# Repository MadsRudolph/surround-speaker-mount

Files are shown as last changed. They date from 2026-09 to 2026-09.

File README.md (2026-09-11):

# Surround speaker wall mount — compact revision 3

The **[Eris E3.5 dorm-room rail adaptation](rail-mount/README.md)** has its own CAD, print files, concrete-through-rail fixing layout and furnished room renders. It provides ±90° pan and 0–60° indexed downward tilt; see its separate prototype and installation notes.

Three printed parts per speaker, identical for left and right. Default cabinet: **150 × 150 × 180 mm**. Designed motion: **continuous ±60° yaw; 0° to −30° pitch in 5° steps**. All CAD coordinates and STL coordinates are millimetres. This is an unqualified prototype: speaker mass, cabinet construction and wall substrate were not supplied; panel height and plug projection remain unconfirmed. There is no assigned safe working load or claim of permanent freedom from droop.

## Download and print

The **[print/](print/)** folder contains the three current, print-oriented STLs. Download **[speaker-mount-print-STLs.zip](speaker-mount-print-STLs.zip)** for all three plus a quick print guide. Print **two of each part** for a left/right pair.

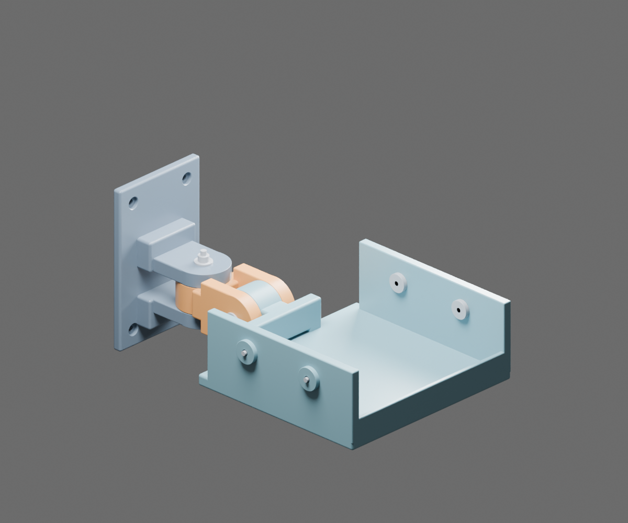
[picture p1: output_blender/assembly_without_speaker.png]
Compact assembly


For live mouse control in FreeCAD, run **[Open_Interactive_Assembly.FCMacro](Open_Interactive_Assembly.FCMacro)**: drag horizontally for pan and vertically for tilt. See [interactive instructions](INTERACTIVE_ASSEMBLY.md).

## Revision 3: indexed tilt, continuous pan

Only the **second (up/down) pivot** has mating radial serrations. The first
(left/right pan) pivot keeps its smooth friction faces and continuous adjustment.
The tilt interface has **72 teeth, giving 5° steps**: 0°, −5°, −10°, −15°, −20°,
−25° and −30°. Three main printed parts are retained; the wall plate is unchanged.

The arm's left inner cheek has a recessed female ring; the cradle's left pitch
face has the matching raised ring. Teeth occupy radii **16–21 mm** of the existing
44 mm joint. Male relief is **0.45 mm**, female groove depth **0.50 mm**. The
trapezoidal profile has broad crests/valleys, with a minimum nominal crest width
of about **0.42 mm** at the inner radius. Small flank/root relief leaves room for
fit variation; zero backlash is not promised.

**Adjustment:** support the speaker, loosen the tilt bolt, slide the cradle toward
the opposite smooth cheek to disengage the teeth, choose a 5° position, seat the
teeth and retighten. Do not force the teeth to ratchet under load. The two nominal
0.3 mm face gaps provide **0.6 mm axial travel from seated to released**, leaving
**0.15 mm nominal tip clearance** at release. Only one face is toothed so release
does not require spreading both clevis ears. Normal clamping still closes the
assembly clearance; tooth engagement and print tolerances must be checked.

The teeth provide positive angular engagement, but the bolt must keep them seated.
Actual rigidity, tooth strength, wear and long-term holding capacity have not been
measured. This is inspired by the radial face-coupling principle described by
[Voith](https://www.voith.com/corp-en/products-services/connection-components-couplings/hirth-serrations.html),
not a rated industrial Hirth coupling.

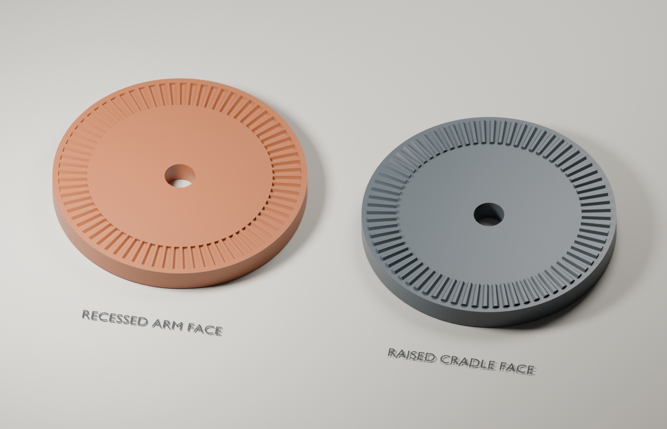
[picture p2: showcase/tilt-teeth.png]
Tilt-only mating tooth profiles on the fit coupons


The two test discs above carry the same tooth profiles as the arm and cradle.
Print the [two fit coupons](print/fit-coupons/) first. Reprint **both the arm and
cradle** for this revision; do not mix a revision 2 smooth part with a revision 3
toothed part. Revision 2 remains available in Git history.

## Compact revision

The pivot spacing is now **55 mm instead of 100 mm (45% shorter)**. The slender connecting span is replaced with a short, wider connector. The speaker rear face sits **147 mm from the wall instead of 197 mm**, a 50 mm reduction. The rear support is only 36 mm high, instead of 102 mm, and the wall plate is 140 mm tall instead of 160 mm. Both full ±60° pan and −30° tilt are retained in the sampled clearance checks. Further wallward shortening consumes the clearance needed when the wide tray is turned 60°.

Your terminal description is interpreted as a centered 40 mm-wide panel (150 − 2×55), with its lower edge 40 mm above the speaker bottom. The tilt pivot is lowered to Z=24 mm, leaving the hardware below the panel. Panel **height is provisionally 60 mm** and connected-plug projection is provisionally **30 mm**. A 50 mm-wide × 70 mm-high clearance box includes 5 mm border margin around that assumed panel, extending 30 mm behind the cabinet. This box is included in the collision checks. The panel is shown in black in Blender; its assumed height is named explicitly in the scene.

The compact geometry reduces the free arm span, but stiffness has not been measured. A lower pivot also changes the gravity torque at downward tilt: the load notes below have been updated rather than assuming every load decreases. `revision_1_original.zip` preserves the previous design locally; the main ZIP contains the current revision 3.

## How this will look

A Blender living-room showcase places the current mount geometry in an illustrative
surround setup with a TV, couch and mounted speakers. The unbranded cabinets match
the design envelope; these are concept renders, not a tested installation.

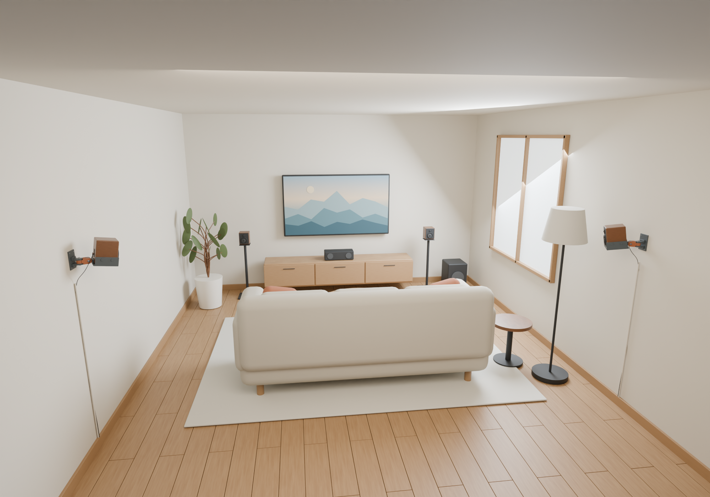
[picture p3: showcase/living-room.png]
Living-room surround setup


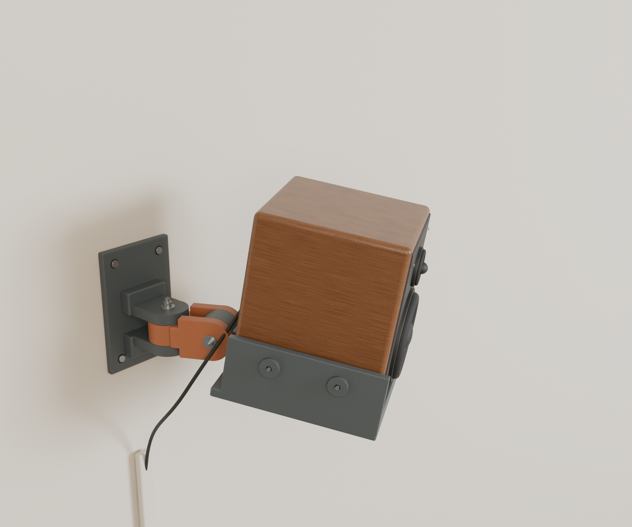
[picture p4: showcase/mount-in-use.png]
Mount with speaker installed


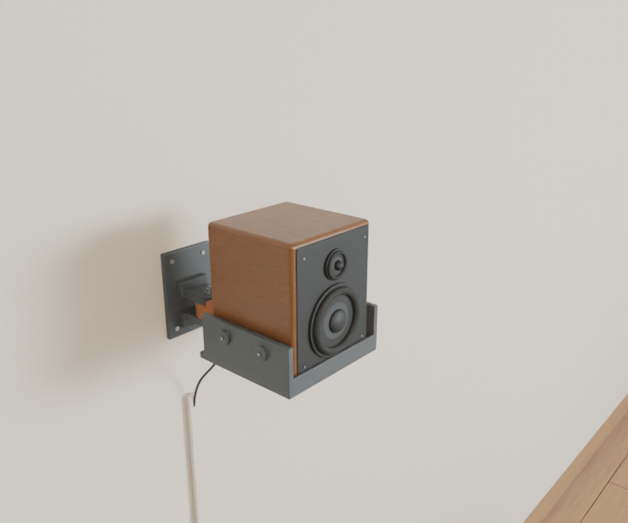
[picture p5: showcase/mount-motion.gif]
Continuous pan and indexed tilt animation


The tilt joint releases axially, changes by 5°, and re-seats. Pan stays continuous.

See [showcase/](showcase/) for the editable Blender scene, rendering script and details.

## Interactive assemblies

Open `output_blender/interactive_assembly.blend` or `output_freecad/interactive_assembly.FCStd` to pose the mount. See [INTERACTIVE_ASSEMBLY.md](INTERACTIVE_ASSEMBLY.md) for the two angle controls and optional FreeCAD slider macro.

## Files and execution

- `parametric_mount.py`: standalone FreeCAD script; Spreadsheet-driven scripted PartDesign bodies.
- `blender_mount.py`: standalone `bpy` model builder, articulated scene, mesh validator, STL exporter and render.
- `output_freecad/`: FCStd, STEP, three print-oriented STL files and CAD validation reports.
- `output_blender/`: Blender scene, assembly image, three print-oriented STL files and mesh report.
- `validate_cad.py`: sampled collision and parameter dependency checks; imports `parametric_mount.py`.
- `geometry_spec.py`: readable geometry reference. Each standalone builder contains its own copy, so neither requires this file. When changing geometry, keep both builders consistent.
- `FREECAD_MCP_SETUP.md`: detection and connection instructions.

Run on this machine:

```bash
cd surround-speaker-mount
python parametric_mount.py
python validate_cad.py
blender --background --factory-startup --python blender_mount.py
```

System Python works here because the script finds `/usr/lib/freecad/lib`. On another OS, run in FreeCAD's Python console:

```python
import sys
sys.path.insert(0, '/absolute/path/to/surround-speaker-mount')
import parametric_mount
parametric_mount.build()
```

Each execution makes a new document/scene and replaces generated output files. Blender preserves other scenes in its current session; use the background command above for a clean deliverable. Rendering uses CPU Cycles. No external assets or Python packages are required by the Blender script.

To reopen the FreeCAD file **with live recomputation**, add the script directory to `sys.path` and import `parametric_mount` before opening the FCStd. Its three bodies use `PartDesign::FeaturePython` backed by OpenCascade solids, not a conventional sketch/Pad/Pocket feature history. Each feature's dimensional properties are expression-linked to `Parameters`. Edit the spreadsheet and recompute. The file's saved shapes remain viewable without the module, but live rebuilding requires it. Re-export after edits:

```python
from pathlib import Path
import FreeCAD as App
import parametric_mount as m
doc = App.ActiveDocument
doc.recompute()
m.export(doc, [doc.getObject(n+'_Geometry') for n in m.NAMES],
         Path('/absolute/path/to/surround-speaker-mount/output_freecad'))
```

| Spreadsheet alias | Default | Effect |
|---|---:|---|
| Speaker_Width | 150 mm | Tray span, sides and clamp locations |
| Speaker_Depth | 150 mm | Tray depth, lip and clamp spacing |
| Speaker_Height | 180 mm | Side rail and clamp height |
| Clamp_Padding_Offset | 2 mm | Cabinet padding allowance |
| Insert_Hole_Diameter | 5.6 mm | Four M4 insert bores |
| Wall_Thickness | 4 mm | Lip; structural plate/rails use twice this value |

Structural thicknesses deliberately exceed 4 mm: tray 10 mm, wall plate 8 mm, side rails 8 mm, clevis ears 12 mm. Numeric parameter bounds reject grossly unsuitable dimensions; they do not certify every combination for clearance or strength. Recheck motion after changing dimensions. Blender uses the `DEFAULTS` dictionary near the top; it does not synchronize automatically with an edited FCStd.

## Geometry and joints

Wall plate: 90 × 140 × 8 mm, with four Ø4.8 mm screw passages on a 60 × 110 mm rectangular pattern. Ø10 × 3 mm counterbores have 0.5 mm radial, 45° mouth chamfers. Rounded edges are generally 1–2 mm. The plate's wall-contact plane is Y=0; its front is Y=8.

Yaw axis is vertical at (0,55,24); pitch axis runs left–right at (0,110,24). Both joints have 44 mm diameter faces and Ø5.3 mm bolt bores. Yaw faces are smooth; one pitch interface carries the revision 3 tooth ring. Wall clevis spacing is 24 mm with a 23.4 mm middle knuckle; pitch clevis spacing is 24.6 mm with a 24 mm tongue. **0.3 mm nominal clearance per mating face**, 0.6 mm total, is taken up when tightening. Washers go outside the ears, not in these gaps. Keep yaw friction faces dry and flat, and keep tilt teeth clean. Yaw is continuous; tilt seats at 5° increments. Software limits are not physical end stops.

The cabinet rests at Z=12 with 2 mm shelf foam. Rear face Y=147, front face Y=297. Lip inner face Y=299 leaves 2 mm for padding; the 26 mm high lip overlaps the speaker bottom by 14 mm. Clamp rail inner faces X=±81 leave 6 mm per side: **4 mm swivel foot plus 2 mm foam**. Side rails end at Z=68.4; clamp centers are Z=48.6 and Y=190/257.5.

The rear bridge ends at Z=36 mm; the measured panel lower edge is Z=52 mm (10 mm shelf + 2 mm foam + 40 mm cabinet offset). The pitch knuckle top is Z=46 mm. The centered terminal region above this is open. The provisional terminal-and-plug clearance box spans X=−25…25, Y=117…147 and Z=47…117 mm. Route wires upward or sideways out of this region, then in a loose service loop clear of both joints. The rectangular clearance check does not simulate a flexible cable or establish a bend radius.

## Hardware BOM

Dimensions below correspond to the default geometry. Count two of each printed part for the pair.

| Hardware | Per speaker | Pair | Specification |
|---|---:|---:|---|
| Yaw and pitch screws | 2 | 4 | M5 × 60 mm socket head cap screws, steel, length under head |
| Joint locknuts | 2 | 4 | M5 nylon-insert locknuts, about 5 mm high |
| Joint load-spreading washers | 4 | 8 | M5, ID 5.3 mm, OD 15 mm, thickness 1.5 mm |
| Clamp screws | 4 | 8 | M4 × 25 mm threaded shaft, commercial ball-ended swivel-pressure screws, detachable feet |
| Swivel pressure feet | 4 | 8 | Ø16 mm, 4 mm effective axial thickness; compatible with selected M4 screws |
| Clamp jam nuts | 4 | 8 | M4, gently lock screw position after setting pressure |
| Heat-set inserts | 4 | 8 | M4, 6 mm long, nominal OD about 6 mm; straight-hole style suitable for selected polymer |
| Wall screws | 4 | 8 | #8 / Ø4.0–4.5 mm, low pan head ≤9.5 mm diameter and ≤3 mm high |
| Wall anchors | As needed | As needed | Matched to substrate, screw and evaluated pullout/shear loads |
| Foam | ~0.8 m | ~1.6 m | 2 mm thick × 20 mm wide closed-cell EVA/EPDM self-adhesive tape |
| Independent retention | 1 | 2 | Rated strap/harness enclosing cabinet, attached to a separate suitable wall fixing |

M5 grip: yaw plastic 48 mm, pitch plastic 48.6 mm; two 1.5 mm washers plus a ~5 mm nut leave roughly 4 mm or 3.4 mm of thread beyond the nut with M5×60. Confirm full nylon engagement with the actual hardware. Nut and head seats remain externally accessible; the model does not rely on printed threads or trapped nuts for the joints.

M4 shaft/foot products have differing length conventions. The model reserves a 12 mm boss/rail depth, 4 mm inward foot thickness and 2 mm foam. Confirm the supplier's drawing gives this working reach and that the foot can be attached **after** threading the shaft through the insert. Do not substitute a bare screw tip against the cabinet. The Blender hardware is an illustrative envelope, not a manufacturing drawing of purchased components.

The 5.6 mm insert hole is a starting value, **not a universal M4 standard**. Buy an insert whose specified installation hole matches your print, or change the parameter. Install from the **cabinet-facing side** so the clamp reaction tends to push the insert into its boss. The 12 mm through-bore leaves travel behind a 6 mm insert. Test an isolated boss cropped in the slicer before printing the full tray. Hole sizing, polymer and boss dimensions determine insert performance; follow the [insert manufacturer's guidance](https://www.spirol.com/resources/white-papers/how-to-design-the-proper-hole-for-heat-ultrasonic-inserts/).

Wall screw **length cannot be finalized without the wall build-up**. Example only: 4.5 × 60 mm screws through the remaining 5 mm counterbore floor and 12.5 mm plasterboard leave 42.5 mm nominal penetration into timber. Verify screw/anchor manufacturer requirements and obstructions. The 60 mm wide hole pattern does not put all four screws into one narrow stud: use structural backing spanning studs, suitable masonry fixing, or a verified anchor arrangement. Do not assume a generic drywall anchor is adequate.

## Printing and assembly

Use PETG or ASA with a validated filament profile. ASA needs suitable enclosure and ventilation; see [Prusa's ASA guidance](https://help.prusa3d.com/article/asa_1809?product=mk3-5) and [PETG guidance](https://help.prusa3d.com/article/petg_2059?product=mini). Neither material makes this a creep-free joint; the tilt teeth also require fit and wear checks. The following settings are design recommendations, not measured strength data:

- 0.4 mm nozzle, 0.20 mm layers; **6 perimeters**, 6–8 top/bottom layers, **45–50% gyroid**.
- Set local solid infill around pivot ears, arm roots, rear cradle supports and insert bosses. At least 4–5 walls and 35% infill as requested; the higher values above provide a more conservative starting point.
- Print all three parts **on their X side**, as already oriented in the exported STLs. The arm is flipped relative to revision 2 so its female tilt face points up; the cradle's male tilt face also points up. This places the main Y–Z cantilever bending plane within printed layers. It reduces the critical delamination tendency; it cannot eliminate every transverse tensile stress in a two-axis bracket.
- Use 0.10–0.12 mm layers through the toothed region and verify that the slicer preserves the teeth. Use support blockers on the serrated face; route supports for the opposite ear from smooth regions or the bed. Print and hand-fit the coupons first.
- Use removable supports under raised rails, upper clevis ears, bosses and horizontal bores; inspect the layer preview. Support is not limited to the build plate if that leaves internal overhangs unsupported. Use a brim and protect friction surfaces when removing supports.

| STL | Print bounding box X × Y × Z |
|---|---|
| Part_1_WallPlate | 140 × 77 × 90 mm |
| Part_2_SwivelArm | 44 × 99 × 48.6 mm |
| Part_3_Cradle | 68.4 × 215 × 186 mm |

A **250 mm bed** is recommended for cradle supports and brim; a 220 mm bed leaves only 5 mm total margin in the long direction before supports/brim. STL files are unitless by convention: import as millimetres, verify these dimensions, and do not auto-scale. Print a second identical set for the opposite surround. Do not mirror only one mating part.

1. Confirm speaker mass, terminal clearance, pressure-foot dimensions and wall fixing design. Measure the printed bores and check slip fits before heating inserts.
2. Remove supports, deburr, and carefully finish M5 holes to 5.3 mm if needed. Do not enlarge insert bores without the insert data sheet. Reject split layers or under-extruded parts.
3. Heat-install four M4 inserts from inside the cradle; use a perpendicular installation tip and allow full cooling. Attach the pressure feet after threading the clamp screws through the inserts.
4. Place two 150 mm foam strips on the shelf, foam on the front lip and rear contact columns, and Ø16 mm foam disks on the four pressure feet. Keep foam away from pivot friction surfaces.
5. Assemble yaw and pitch using M5×60 screws, one washer under each head and one under each locknut. Snug the yaw joint until friction is established. Fully seat the tilt teeth at a 5° position before tightening its bolt. Do not apply a generic steel-joint torque value: the plastic seats and ears are the limiting components.
6. Seat the speaker fully on the padded shelf. Tighten the four pressure screws evenly until it is retained without visible cabinet deflection. Gently snug jam nuts while holding each screw. The shelf and lip carry gravity/sliding loads; clamps are not permission to crush the enclosure.
7. Test the complete assembly with a restrained dummy load close to the floor before wall installation. Establish required holding torque and monitor tilt, ear gap and permanent deformation over an extended dwell at expected room temperature. A short test does not establish long-term life. Add independent cabinet retention for overhead use.
8. Remove the speaker, fasten the plate to the evaluated wall fixings, then reinstall and aim it. Hand-support the speaker while loosening either joint. Keep yaw within ±60° and tilt within 0° to −30° in 5° steps. Disengage the tilt teeth before turning, then seat and retighten. If it drifts, rocks or fails to engage, stop and inspect or redesign the joint instead of overtightening.
9. Reinspect after initial settling and periodically thereafter. Inspect the tilt teeth for incomplete seating, wear, cracking and debris. Printed teeth do not establish maintenance-free holding; nylon locknuts alone do not provide that function.

## Load assessment and verification limits

For a uniformly distributed default cabinet, its center is approximately Y=222, Z=102. Relative to the new pitch pivot, that is 112 mm forward and 78 mm upward. The horizontal pitch lever arm is 112 mm at level and **136 mm at −30°**. Speaker-only torque is therefore **1.099 × mass_kg N·m** at level, rising to **1.334 × mass_kg N·m** at −30°. Wall torque is **2.178 × mass_kg N·m** at level and **2.413 × mass_kg N·m** at −30°. Add the cradle, arm, hardware, cable forces and handling loads. A 2 kg cabinet alone at −30° produces about 2.67 N·m at pitch and 4.83 N·m at the wall; this is not a 2 kg rating.

The original pitch friction-capacity estimate no longer describes the revision 3
load path. Tilt torque now loads the tooth flanks, while bolt preload must resist
separation and keep them engaged. The nominal tooth geometry is not a strength
rating: print accuracy, root stress, uneven tooth contact and polymer creep still
need assessment. Yaw continues to rely on friction. FEA, coupon load tests and a
load-duration test have not been performed.

The CAD validator checks 91 sampled pan/tilt positions (10°/5° increments) against the wall, fixed plate, arm, cradle, cabinet envelope and the provisional terminal/plug envelope. It also changes all six spreadsheet parameters individually and verifies recomputation into single valid solids. This is not continuous swept-volume proof; purchased fasteners, flexible cable loops, foam compression and deformation are excluded. Blender independently checks zero nonmanifold edges, one connected component and positive enclosed volume before STL export. Meshes approximate the analytic CAD fillets, so small volume differences are expected.

Final export verification also re-imported all six STLs into FreeCAD Mesh: all reported closed solids with no nonmanifold edges (`stl_validation.json`). Revision 3 needed no boundary repairs. The Blender script retains a tightly limited small-quad repair for Boolean artifacts, then rejects any remaining nonmanifold geometry. Runtime: FreeCAD 1.1.3, Blender 5.2.0. The local Blender installation emitted an unrelated bundled-addon `cattrs` import warning; model generation, both renders and export checks completed.

The revision 3 tilt validator (`validate_tilt_index.py`) checks all seven indexed
positions at nominal and seated offsets, confirms interference at every half-step
when seated, and checks 61 released positions at 0.5° intervals. It exports the
fit coupons and `output_freecad/tilt_index_validation.json`. These are geometric
checks, not strength or wear measurements.

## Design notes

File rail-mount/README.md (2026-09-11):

# Eris E3.5 mounts for the dorm-room rail — revision 1.1

Two adjustable mounts at the wooden rail's existing height, anchored **through the wood into concrete**. Every fixing axis stays within the rail's 50 mm-high outline. Sized for the original PreSonus Eris E3.5 / E3.5 BT, **141 W × 162 D × 210 H mm**.

This is a complete CAD prototype with print files and sampled geometric verification. It has **no assigned safe working load** and has not undergone physical print-fit, creep, sustained-load or anchor testing. Establish those before installing above the bed.

Revision 1.1 enlarges the two inner tilt-bolt recesses to Ø32 mm so a nominal 4 mm-thick spanner can counterhold the heads. The pivot bores, teeth, cabinet fit and movement envelope are unchanged; only the cradle STL needs replacing if you already printed revision 1.0. Side foam now has a 36 mm-wide tool window above Z=−18 mm relative to the pitch axis.

New files: [1:1 A4 drilling template](cad/drilling-template-A4-100percent.pdf), [adjustable isolated mount scene](render/mount_inspection.blend), [speaker-removed service view](render/mount-service.png), and [bolt/spanner fit coupon](print/fit-coupons/Tilt_Bolt_Tool_Access.stl).

Print the template at **Actual Size / 100%**, and measure both scale bars. It transfers centres only: choose drill diameter and depth from the actual concrete-fixing instructions. Do not drill a Ø14.2 hole in the concrete just because that is the printed sleeve bore.

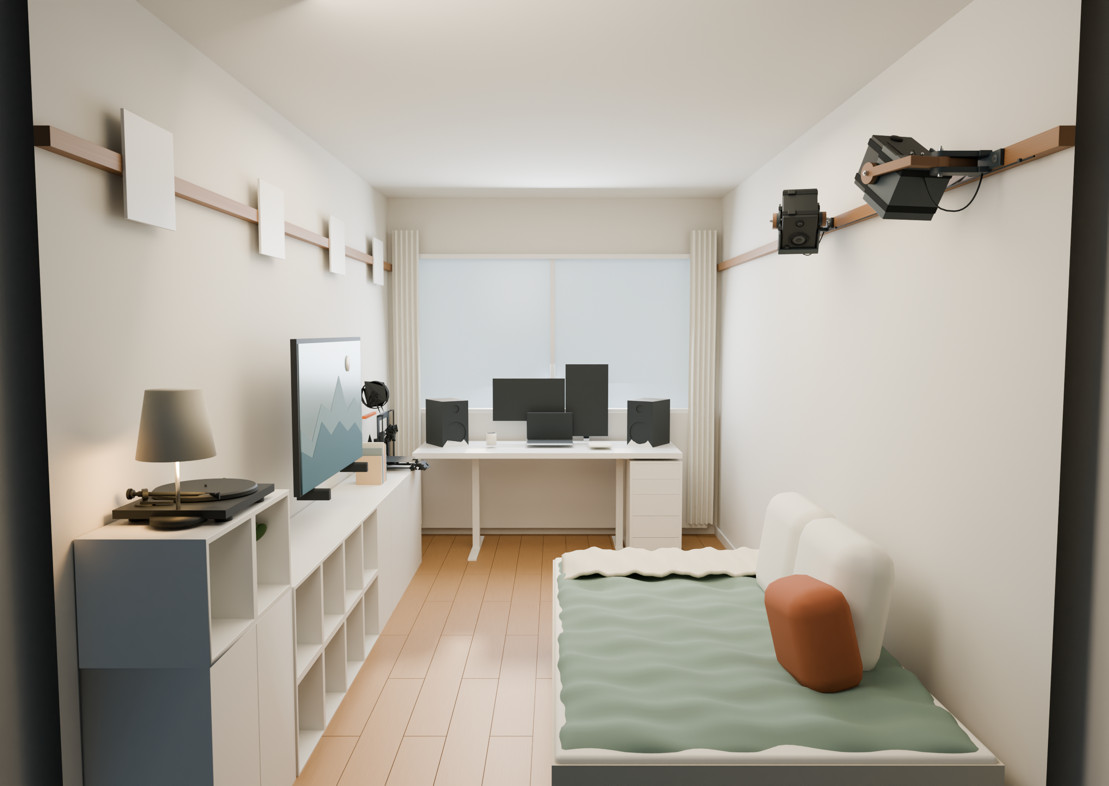
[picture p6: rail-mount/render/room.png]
Room


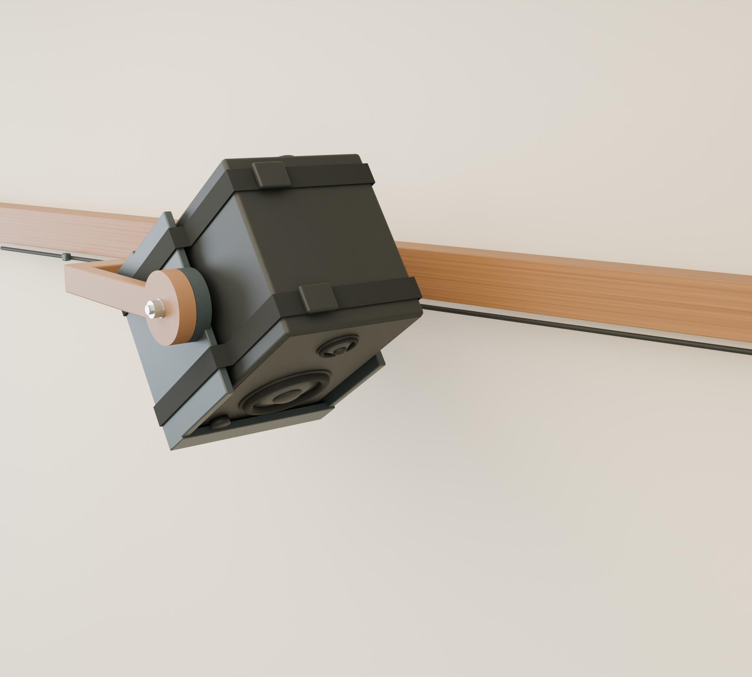
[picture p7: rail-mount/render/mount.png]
Rail mount


## Files

- [Dimensioned drawings and assembly guide](cad/mount-drawings.pdf) — three pages; dimensions, fixing locations, BOM and adjustment.
- [FreeCAD assembly](cad/eris_rail_mount.FCStd) — native solid parts, hardware envelopes and speaker envelope, in the level reference pose.
- [STEP](cad/eris_rail_mount.step) — the three mount solids, in assembly coordinates; import into Fusion.
- [Print files](print/) — one shoe, yoke and cradle per speaker; print **two of each**.
- [Fit coupons](print/fit-coupons/) — new 5-degree tooth profiles, different from revision 3.
- [Editable room scene](render/dorm_room.blend) — actual imported architecture/furniture, both mounts and adjustable aiming controls.

> **Not in the repository.** `render/dorm_room.blend`, `render/room_meshes.json` and the two packaged zips are large binaries, and the room mesh is imported architecture rather than anything in here rebuilds, so they are kept local. Everything needed to print and install the mount — CAD, STEP, STLs, drawings and the drilling template — is committed. Run `rail-mount/package.py` against a local working copy to rebuild the render pack.
- [Room image](render/room.png), [mount detail](render/mount.png), [cutaway](render/overview.png), [both speakers above the bed](render/rail-wall.png).
- [Verification report](cad/validation.json), [solid validation](cad/geometry_validation.json).

## Mount arrangement

The 180 × 46 × 12 mm shoe bears against the timber face. Two fixing centres are **130 mm apart**, on the rail's horizontal centreline. A yaw clevis projects into the room; a U-shaped yoke supports the cradle at both sides near the cabinet's geometric centre. Two short outward-facing tilt bolts stay outside the speaker cabinet. There is no shaft through the speaker and no cabinet drilling.

Movement is **continuous ±90° pan** and **0–60° downward tilt in 5° steps**. These are permitted operating limits, not mechanical stops. Left-side radial teeth provide positive tilt indexing. Right side is smooth. Fully seated to released axial travel is 1.0 mm: the 0.8 mm male teeth then have nominal 0.2 mm tip clearance. Both tilt nuts must be loosened for release. Do not force the teeth to ratchet under load.

The shelf, padded stops and two 20 mm webbing loops retain the speaker. The loops pass under the shelf in the two shallow channels and close on top, leaving the front drivers free. Use 4 mm base padding, 6 mm side padding and 2 mm front/rear stop pads. Final foam compression and actual cabinet fit need checking. The CAD provides a 50 mm-deep rear connector/port allowance, 130 mm wide, from 60 mm below to 96 mm above the pitch axis. Real cable loops, buckle shapes and port airflow need physical checking.

## Starting positions in this room

Coordinates measured **along the rail from the window-end wall**:

| Item | Window-side / right surround | Far-side / left surround |
|---|---:|---:|
| Mount centre | 2646 mm | 4060 mm |
| Fixing holes | 2581, 2711 mm | 3995, 4125 mm |
| Starting pan | +76.10° | −76.10° |
| Starting downward tilt | 55° | 55° |

Both mounts were moved inward from the first layout so the far-side speaker clears the end wall throughout the sampled movement range.

All four fixing axes are **2075 mm above the modeled floor**, at the rail centreline. The plate's top and bottom have 2 mm nominal margin within the rail face. The far-side plate ends at 4150 mm, leaving 250 mm to the modeled rail end. Verify the real rail and concrete edge conditions before using these positions.

Aiming assumes your ears are 350 mm from the wall, at the bed's midpoint (3353 mm from the window end), and 1400 mm above the floor. Your height does not determine exact seated ear position: this remains an estimate. An approximate tweeter point gives about **860 mm speaker separation** after toe-in and approximately 0.78 m from each tweeter to your ears. The 55° indexed settings miss that estimated point by less than 0.7°. Fine-tune the pan and choose an adjacent tilt index after sitting down.

The pivot axis stays at rail height; rotating a cabinet necessarily moves its corners above and below that axis. No drop bracket is used.

## Hardware — quantities per speaker

| Hardware | Quantity | Notes |
|---|---:|---|
| M8 × 80 hex-head bolt | 1 | Yaw; nominal 13 mm across flats, 5.3 mm head height |
| M8 × 45 hex-head bolt | 2 | Separate left/right tilt bolts, inserted from inside outward |
| M8 locking nut | 3 | Nominal 8 mm high; verify supplied hardware |
| M8 washer | 6 | Ø16, 1.6 mm thick; one at each head/nut |
| Metal tube sleeve | 2 | Ø14 outer, ID11, cut to 12 mm; sits in printed Ø14.2 bores |
| Anchor load-spreading washer | 2 | Ø24, ID10.5, 2 mm thick |
| Concrete fixing assembly | 2 | Selected for the actual concrete, edge distances and fixture |
| 20 mm retaining webbing loop | 2 | Approximately 0.8 m stock per loop; trim after fitting; buckle on top |
| Foam padding | As above | Thin closed-cell pads, not thick soft cushioning |

Do not substitute taller socket-head screws at the inner tilt positions without checking the cabinet clearance. Nominal hex-head clearance to the speaker is only 2.6 mm before tolerances. A nominal 30 mm-wide, 4 mm-thick spanner head with a 100 mm handle passed 78 access samples (both sides, all tilt indices, ±15° handle swing), with a 2.9 mm nominal gap to the cabinet. A Ø20 × 40 mm outer socket access envelope also cleared. Check your actual tools with the coupon; larger tools are not covered. Cut back the side padding at the opening before assembly.

The metal sleeves limit compression of the printed shoe under the anchor washers; the timber is still part of the bearing interface.

### Through-rail concrete fixings

The fixture stack is **40 mm wood + 12 mm shoe + 2 mm washer = 54 mm**, plus any actual gap or finish between wood and concrete. Concrete embedment must be added to this; the timber is not embedment. The two bores accommodate an anchor body up to nominal Ø10 inside the metal sleeves. Long shanks in the CAD/render illustrate the fixing axes; they are not models of a selected proprietary anchor.

Choose a concrete-approved fixing for this stack, its required embedment, minimum spacing and actual concrete edge distances. A nominal 140 mm fixing leaves 86 mm beyond a 54 mm stack geometrically, but that arithmetic alone does **not** establish effective embedment or suitability. Do not infer a drill depth, torque or load rating from the CAD. Fischer's [SXRL product documentation](https://www.fischer.co.uk/en-gb/products/frame-fixings/frame-fixing-sxrl/frame-fixing-sxrl-with-countersunk-head-screw) is one manufacturer reference for through-fixings; use the exact selected product's instructions and supplied matching screw.

All installed fixing holes pass through the wood. No fixing above or below the rail is proposed. The narrow plate transfers overturning forces through its timber bearing area and the anchors, so tight, sound timber and suitable concrete fixing design matter even though screws reach concrete.

## Printing and assembly

STLs are in **millimetres**, already oriented on their X side. Keep the supplied orientation unless reassessing layer strength. The principal arm bending plane is then within layers. Supports are required around elevated ears, cross-members and the far side of the cradle. Do not let supports damage the teeth or friction faces.

| Part | Supplied print X × Y × Z |
|---|---:|
| Rail shoe | 61 × 161 × 180 mm |
| Pan yoke | 64 × 243 × 221 mm |
| Cradle | 151 × 180 × 189 mm |

Allow support and brim space. A **250 × 250 × 250 mm or larger** build volume is the practical starting point; the yoke leaves little brim space along its 243 mm dimension. The supplied yoke orientation exceeds a 200 mm build height. The Prusa printer modeled in the room is not proof that these files fit your available printer.

PETG or ASA is a starting material choice, not a strength rating. Start with 6 perimeters, 6 top/bottom layers and 50% infill, with solid regions at bolt bores, teeth and arm roots. Use 0.20 mm layers generally and 0.10–0.12 mm in the tooth-profile regions. Inspect the sliced teeth. Nylon locknuts prevent easy nut loosening; they do not prevent printed plastic creep.

1. Print the two tooth coupons and the new bolt/tool-access coupon. Check tooth seating/release, then fit the actual M8 bolt and 1.6 mm washer and try the spanner before printing the full cradle.
2. Print and inspect all parts. Verify Ø8.5 pivot clearances and sleeve fit; reject split layers, voids or damaged teeth.
3. Insert each tilt bolt and its inner washer from inside the cradle before placing the cradle in the yoke. Fit outer washers and locking nuts. Join yoke and shoe with the yaw bolt.
4. Fit pads with the tool windows relieved, the actual speaker and both retaining straps. Ensure bolt heads, straps and cable plugs clear at the intended angles.
5. Test with a restrained dummy load close to the floor, including prolonged dwell at operating temperature and the worst permitted poses. The individual powered/passive cabinet masses must be measured; the manufacturer's 2.9 kg figure is for the pair.
6. Have the selected concrete anchorage checked for the substrate and load path, then install through the marked rail positions following that product's drilling/cleaning/torque instructions.
7. Provide independent overhead retention that bypasses the printed load-bearing joints, attached using permitted through-rail concrete fixing locations. The two cradle straps retain the cabinet within the cradle but are not a backup for failure of the shoe or yoke.
8. Aim while supporting the speaker. Loosen both tilt nuts, shift the cradle right to release, select a 5° position, seat the teeth left and retighten. Keep pan within ±90°. Recheck after initial settling.

## What was verified

Three valid, single-solid BReps and closed positive-volume exported STLs. **247 combined pan/tilt samples**, pan in 10° increments and tilt in 5° increments, clear the shoe, rail and concrete. All 13 tilt indices clear at nominal and seated positions. Three half-index samples intentionally interfere when seated, and 31 released samples clear. A further 494 poses across the two installed mounts were checked against room end planes, ceiling, floor and opposite wall. Nominal hardware envelopes were also checked against moving components, the cabinet, connector allowance and fixed mounting geometry.

These are sampled rigid-geometry checks, not continuous swept-volume proof. Purchased fastener tolerances, flexible wiring, straps, foam deformation, installation tolerances, print anisotropy, wear and long-term creep are not qualified by these tests.

A uniform cabinet has its centre of mass at the pitch axis, reducing nominal tilt torque. Actual centre of mass is unknown, especially in the powered cabinet. At level and zero pan, the cabinet centre is 360 mm from concrete: **3.53 N·m wall moment per kilogram of speaker mass**, before adding printed parts, hardware or handling loads. At the starting inward pan it is approximately 220 mm from concrete. No strength inference is made from these lever arms.

## Room scene and controls

The architecture, window opening, bed, desk, cabinets, TV, turntable and printer come from `Værelse 65 POP.step`. The two modeled Eris cabinets beside the TV are relocated to the rail. Original desk speakers remain on the desk. Materials, bedding, curtains, small decor and lighting are visualization choices, not claims about your current finishes.

Open `render/dorm_room.blend`. Select **Surround_left / AIM CONTROLS** or **Surround_right / AIM CONTROLS** in the Outliner. In Object Properties → Custom Properties:

- `pan_deg`: −90 to +90, continuous.
- `tilt_step`: 0–12, each step equals 5° downward.

The shoe stays fixed, the yoke pans, and the cradle/speaker tilt together. Cable service loops are illustrative and do not deform automatically with the controls. The rear architecture is hidden from render for the doorway camera; the cutaway additionally hides the near wall and ceiling. The complete imported geometry is retained in the scene.

### Dedicated mount inspection

Open `render/mount_inspection.blend`; the control object is selected. In its Custom Properties, use `pan_deg`, `tilt_step` and `show_speaker`. Switching off `show_speaker` hides the cabinet and straps to expose the cradle, foam tool windows and inner bolt heads. The studio file uses the same CAD meshes as the room scene.

### Channel labels and wiring

Left/right is now explicitly referenced to **you sitting in bed facing the TV**. The window-side position (2646 mm) is the right surround; the far-side position (4060 mm) is the left. Early revision-1.0 labels were swapped; the physical positions and aiming angles are unchanged.

The render places the powered Eris on the window side. With that choice, send the source's **surround-right line output to the Eris L input** (which feeds the powered cabinet), and its **surround-left line output to the Eris R input** (which feeds the passive companion). Run speaker wire between the pair. Confirm with the source's left/right channel test before use. The labels on the Eris inputs describe its internal routing, not a requirement to put the powered cabinet on the left. See the [PreSonus manual](https://pae-web.presonusmusic.com/downloads/products/pdf/ErisE3.5_OwnersManual_EN_V2_23072018.pdf). The source/receiver remains unspecified; this is channel mapping, not a confirmed connection plan for a particular receiver.

## Reproduction

```bash
env QT_QPA_PLATFORM=offscreen python rail-mount/design.py
env QT_QPA_PLATFORM=offscreen python rail-mount/validate.py
env QT_QPA_PLATFORM=offscreen python rail-mount/installation.py
env QT_QPA_PLATFORM=offscreen python rail-mount/make_documents.py
env QT_QPA_PLATFORM=offscreen python rail-mount/fabrication.py
blender --background --factory-startup --python rail-mount/render_room.py
blender --background --factory-startup --python rail-mount/studio_view.py
```

`design.py` contains all dimensions and the new tooth geometry. `render/room_meshes.json` holds the converted STEP geometry; the printer's fine mesh is simplified for rendering. Existing revision 3 files remain separate.

Speaker dimensions and pair architecture: [PreSonus Eris E3.5 / E3.5 BT owner's manual](https://pae-web.presonusmusic.com/downloads/products/pdf/Eris-series_E3.5_E3.5_BT_E4.5_E4.5_BT_OwnersManual_EN_11102019.pdf).

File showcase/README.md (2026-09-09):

# Living-room product showcase

An illustrative 5.1 surround setup with the revision 3 mount on both side walls,
behind the sofa. The room, furniture, speaker cabinets, drivers, materials and
lighting are modelled in Blender. No external models or image assets are needed.

- `living_room.blend`: editable scene, with room and product-detail cameras.
- `living-room.png`: room-wide render.
- `mount-in-use.png`: installed-mount detail.
- `render_living_room.py`: reproducible scene builder and Cycles renderer.
- `scene_manifest.json`: source geometry, cabinet size and mount poses.

Run from the repository root:

```sh
blender -b --python showcase/render_living_room.py
```

Add `-- --preview` for half-resolution previews. CUDA is used when available.
The builder reads `output_blender/surround_mount.blend` and copies the original
mount meshes, scaling millimetres to metres and applying pan/tilt transforms.
It does not change manufacturing geometry or exports.

Speakers are unbranded visual models matching the 150 × 150 × 180 mm cabinet
envelope, not a representation of a verified commercial speaker. Each surround
uses 28° inward pan and 10° downward tilt. Room layout and cables are illustrative;
these renders do not establish load capacity, installation safety or acoustic
performance. Physical fit and load testing remain pending.

## Animated pan and tilt

`mount-motion.gif` is a six-second, 96-frame loop at 720 × 600 pixels.
`mount_animation.blend` contains the animated joints and fixed product camera.
The wall plate stays fixed; the swivel arm turns about the yaw pivot, and the
cradle and speaker tilt together about the pitch pivot. The cable endpoint follows
the speaker while the wall cable cover stays fixed.

```sh
blender -b --python showcase/animate_mount.py
ffmpeg -y -framerate 16 -i showcase/animation-frames/%04d.png -filter_complex "[0:v]split[a][b];[a]palettegen=stats_mode=diff[p];[b][p]paletteuse=dither=bayer:bayer_scale=3:diff_mode=rectangle" -loop 0 showcase/mount-motion.gif
```

Yaw follows ±60° continuously. Tilt disengages axially, advances in 5° steps from 0° to −30°, and re-seats at each step. Frame 97 is the same pose as
frame 1 and is excluded from the GIF to avoid a repeated endpoint. The animation
is a kinematic illustration, not a demonstration of tested load performance.

`tilt-teeth.png` shows the two optional fit coupons carrying the exact arm and
cradle tooth profiles. Recreate it with `blender -b --python showcase/render_tilt_detail.py`;
`tilt_detail.blend` is the editable scene.

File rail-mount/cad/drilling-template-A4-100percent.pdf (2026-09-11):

# ERIS RAIL MOUNT / 1:1 CENTRE-MARKING TEMPLATE

Print at 100% / Actual Size. Disable Fit to Page. Check BOTH scale bars before use.

## WINDOW-SIDE / RIGHT SURROUND — centre 2646 mm

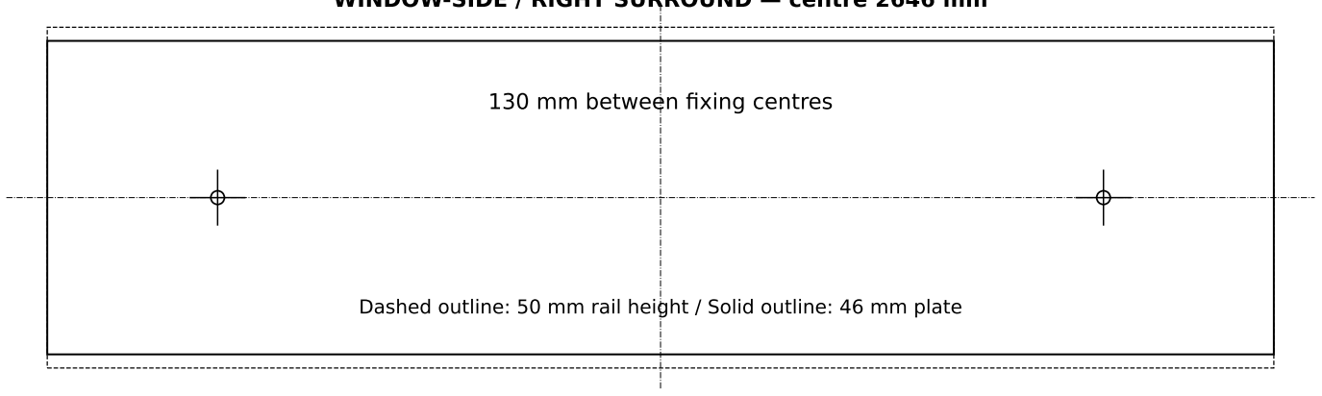
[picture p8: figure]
130 mm between fixing centres

Dashed outline: 50 mm rail height / Solid outline: 46 mm plate

## FAR-SIDE / LEFT SURROUND — centre 4060 mm

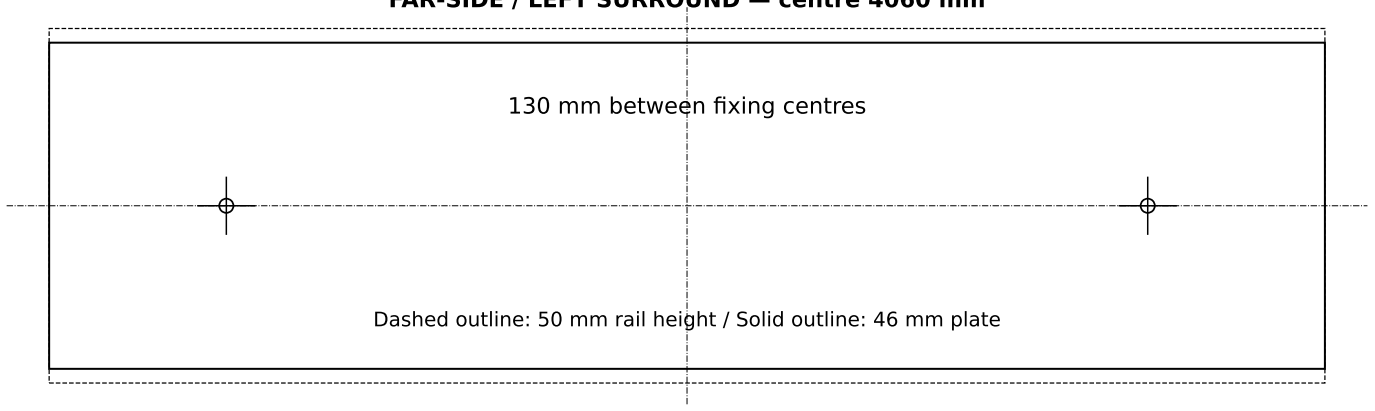
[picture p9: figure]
130 mm between fixing centres

Dashed outline: 50 mm rail height / Solid outline: 46 mm plate

100 mm horizontal scale check

50 mm vertical scale check

TRANSFER CENTRES ONLY. Drill diameters, depth and anchors follow the selected concrete-fixing instructions.

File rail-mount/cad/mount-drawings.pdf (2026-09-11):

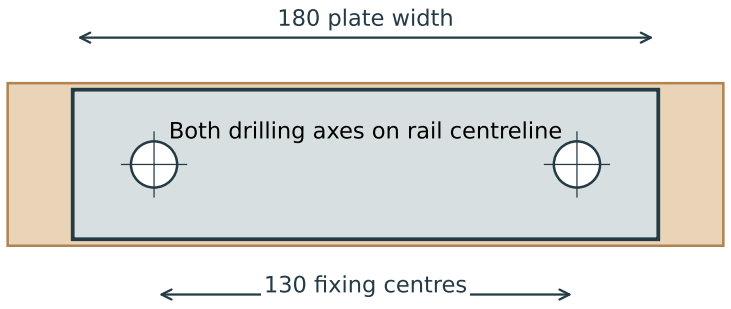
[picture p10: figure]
180 plate width; 130 fixing centres; Both drilling axes on rail centreline

Rail: 50 high × 40 deep. Plate: 46 high × 12 thick. Printed bores Ø14.2 accept Ø14 / ID11 × 12 metal compression sleeves. Anchor body allowance: up to Ø10; washers Ø24 / ID10.5 × 2.

## 01 Fixing interface — front view

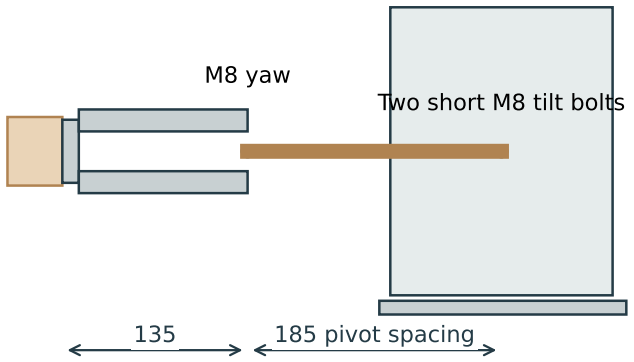
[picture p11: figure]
185 pivot spacing; M8 yaw; Two short M8 tilt bolts

141 W × 162 D × 210 H cabinet

## 02 Side arrangement — level reference pose

# Eris E3.5 / concrete-through-rail mount

ERIS / THROUGH-RAIL MOUNT | • mm | • Prototype: geometric checks only; no assigned working load. | 1

BED

TV

Ears

2646

4060

## 03 Room plan — dimensions from STEP

# Installation / estimated seated listening position

Reference: window end of the room = 0 mm

Rail centre / pivot height: 2075 mm
Rail face projects 40 mm from concrete

Mount centres along rail:
2646 and 4060 mm from window end

Fixing holes along rail:
2581, 2711, 3995, 4125 mm
all at 2075 mm above modeled floor

Starting aim:
window-side +76.10°, far-side −76.10° pan

both 55° down (tilt index 11 of 12)

Estimated ears:
350 mm from wall
3353 mm from window end
1400 mm above floor

Tweeters approx. 860 mm apart after aiming. Ear estimate and tweeter location are provisional. Measure from the real room before marking holes.

ERIS / THROUGH-RAIL MOUNT | • mm | • Prototype: geometric checks only; no assigned working load. | 2

# Assembly / hardware and adjustment

PER SPEAKER

1 × Rail Shoe print
1 × Pan Yoke print
1 × Eris Cradle print

1 × M8 × 80 hex-head yaw bolt
2 × M8 × 45 hex-head tilt bolts
3 × M8 locking nuts
6 × M8 washers, 1.6 mm thick, Ø16

2 × Ø14 / ID11 × 12 mm metal sleeves 2 × Ø24 / ID10.5 × 2 mm anchor washers 2 × concrete fixings (supplier-selected)

2 × 20 mm-wide retaining webbing loops allow about 0.8 m each before trimming 4 mm base foam, 6 mm side foam
2 mm front/rear stop pads

No holes or screws enter the speaker cabinet.

ASSEMBLY

Fit and check the two small tooth coupons first.

Seat the compression sleeves in the shoe.
Insert tilt bolt heads from inside the cradle.
The two bolts point outwards; there is no through-rod. Fit inner washers before fitting the cradle to the yoke.

Add outer washers and locking nuts.
Join yoke to shoe using the M8 × 80 bolt.
Fit pads, speaker and both straps; buckles go on top.

ADJUSTMENT

Pan: continuous within ±90°; support while adjusting. Tilt: 0–60° down, in 5° increments.

Support speaker, loosen BOTH tilt nuts, slide cradle 1.0 mm from its seated left position to the right. Rotate, seat the left teeth, and tighten both nuts. Do not ratchet the engaged teeth under load.

The high-level geometry passes sampled checks. Anchor choice, real print fit, sustained-load testing

and independent overhead retention remain required.

ERIS / THROUGH-RAIL MOUNT | • mm | • Prototype: geometric checks only; no assigned working load. | 3

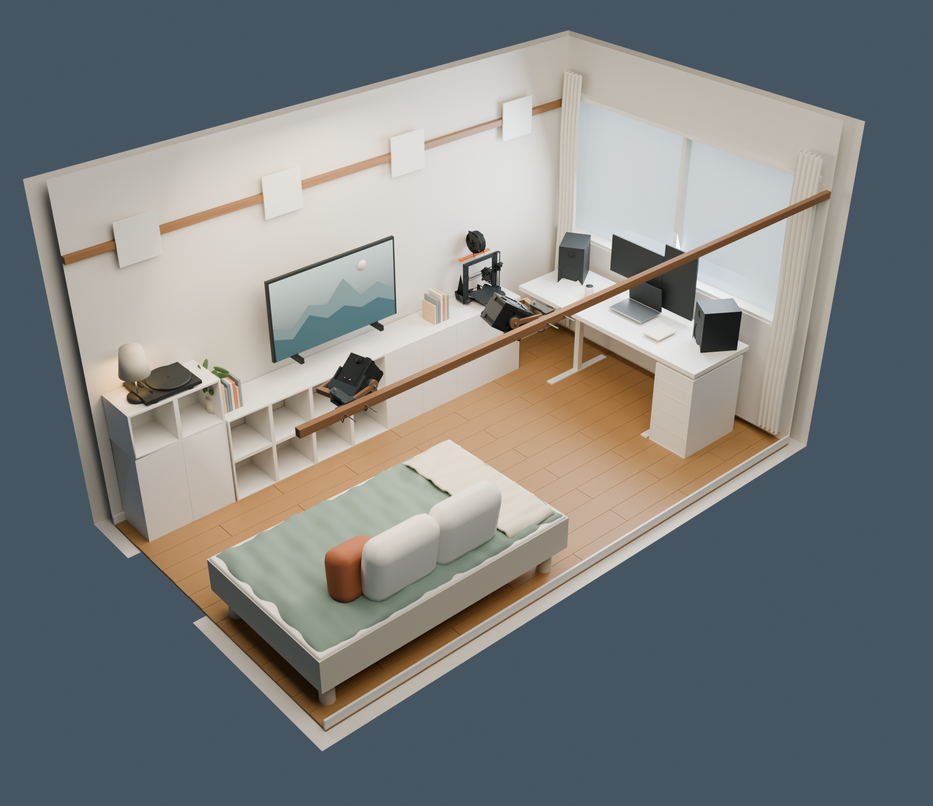
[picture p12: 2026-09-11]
rail-mount/render/overview.png

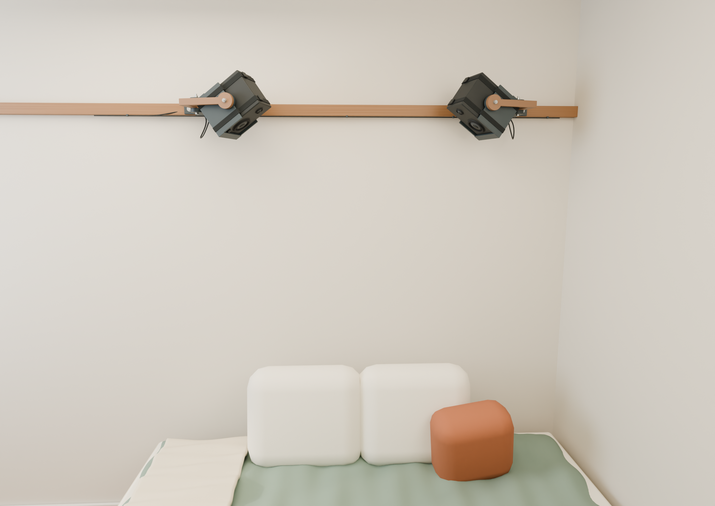
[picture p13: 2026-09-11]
rail-mount/render/rail-wall.png

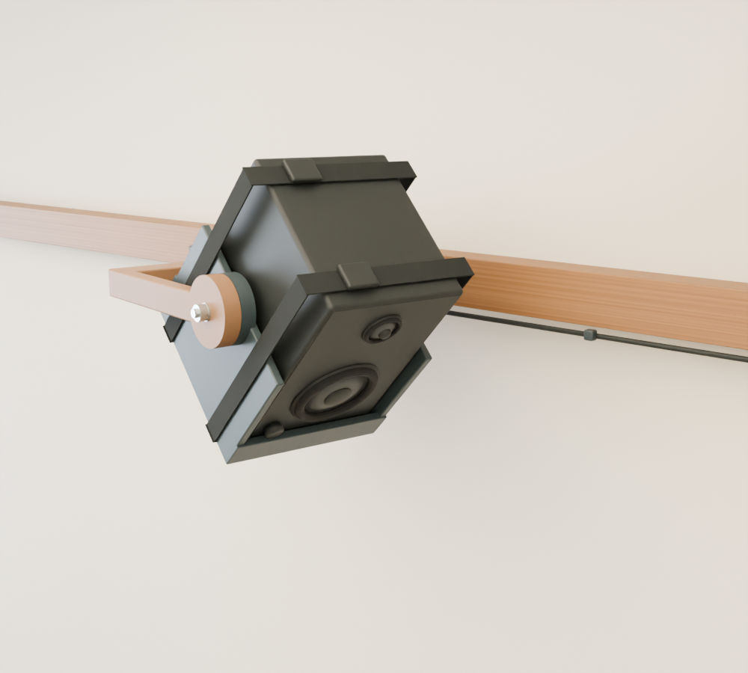
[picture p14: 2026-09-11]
rail-mount/render/mount-preview.png

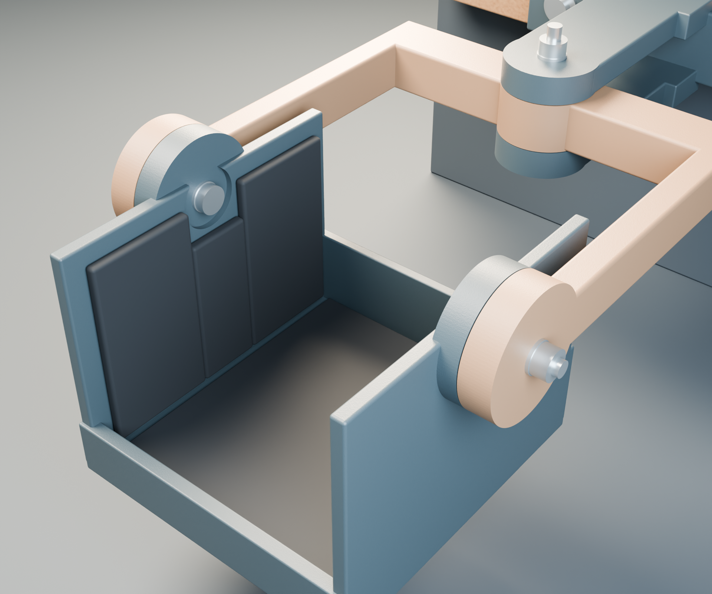
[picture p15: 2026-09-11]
rail-mount/render/mount-service.png

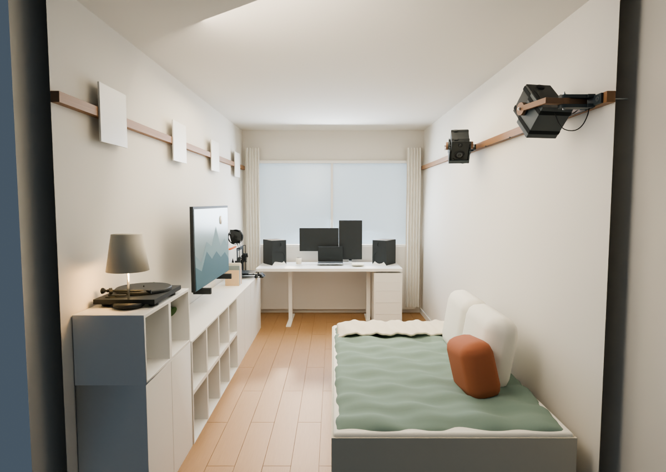
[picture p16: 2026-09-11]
rail-mount/render/room-preview.png

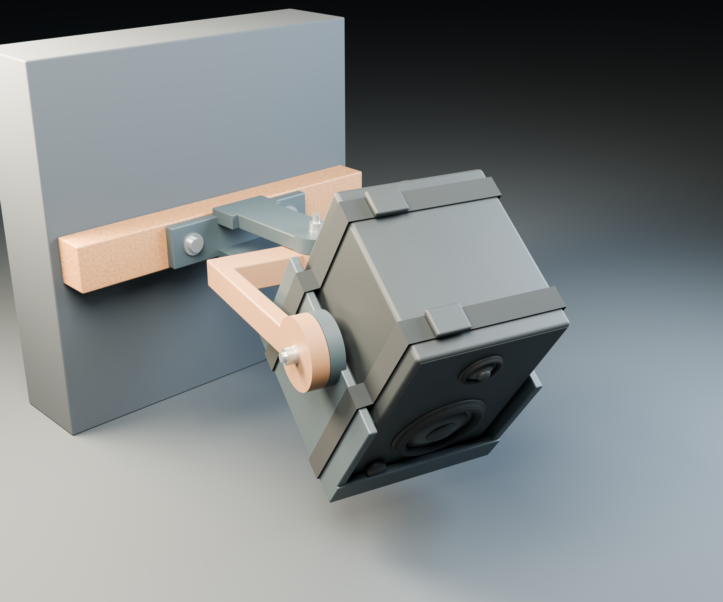
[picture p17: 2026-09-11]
rail-mount/render/mount-studio.png

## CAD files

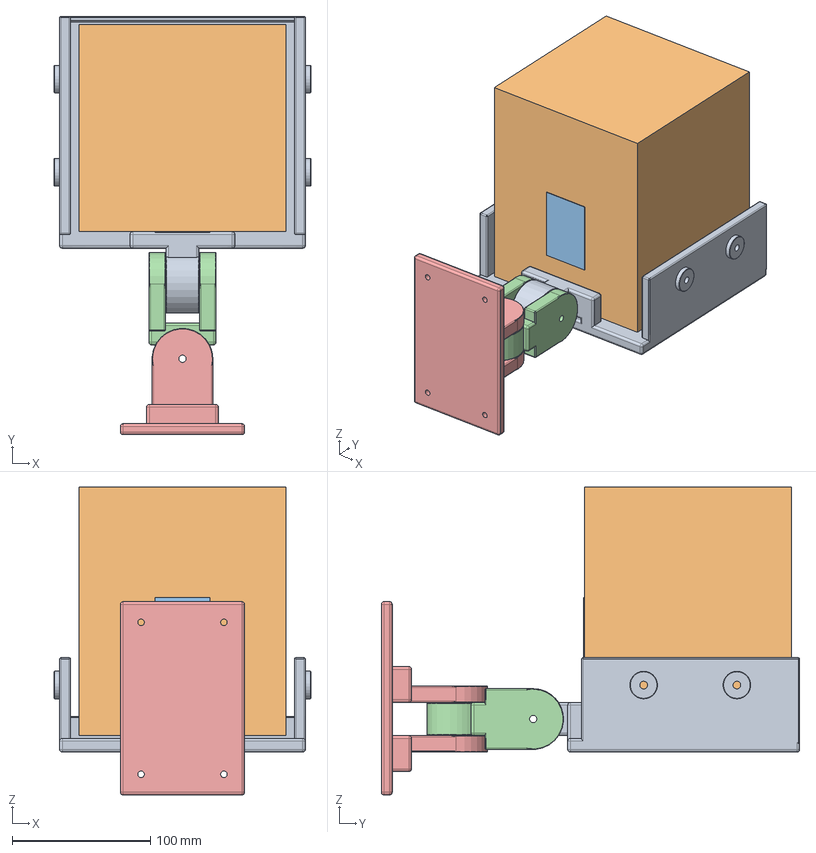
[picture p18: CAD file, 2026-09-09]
output_freecad/interactive_assembly.FCStd
186.0 x 303.0 x 223.0 mm
Part_3_Cradle
Speaker 150 × 150 × 180 mm
Terminal panel — height provisional
Part_2_SwivelArm
Part_1_WallPlate

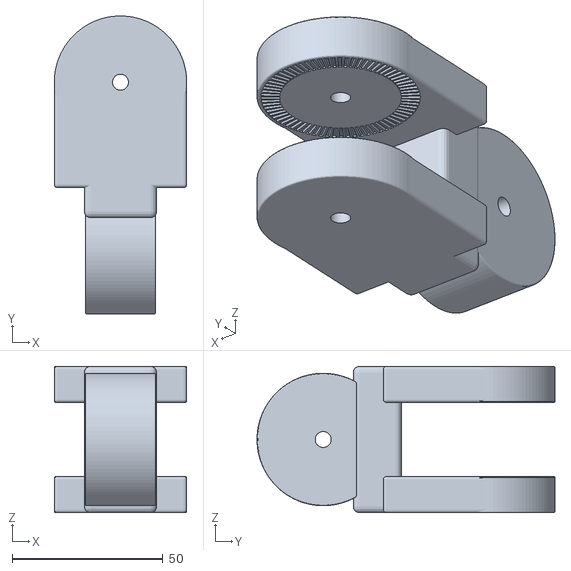
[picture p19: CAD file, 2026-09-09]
output_blender/Part_2_SwivelArm.stl
44.0 x 99.0 x 48.6

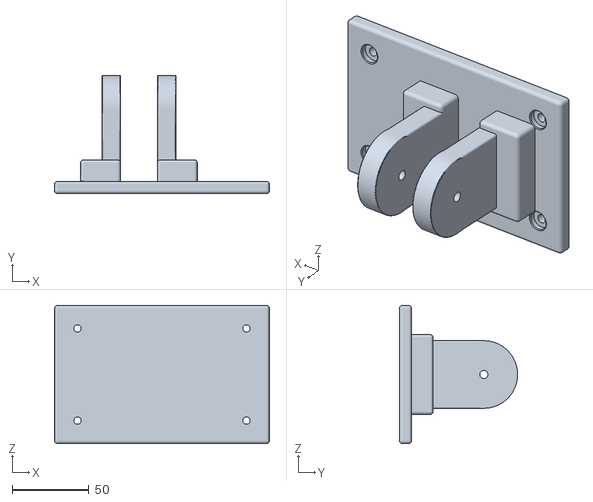
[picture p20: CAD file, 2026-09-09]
output_freecad/Part_1_WallPlate.stl
140.0 x 77.0 x 90.0

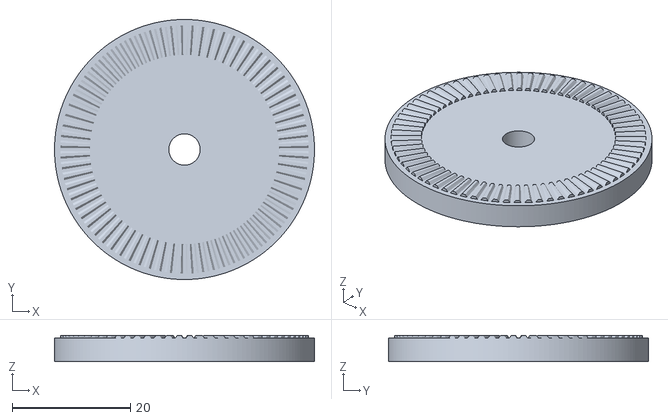
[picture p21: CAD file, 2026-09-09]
print/fit-coupons/Tilt_Male_Coupon.stl
44.0 x 44.0 x 4.45

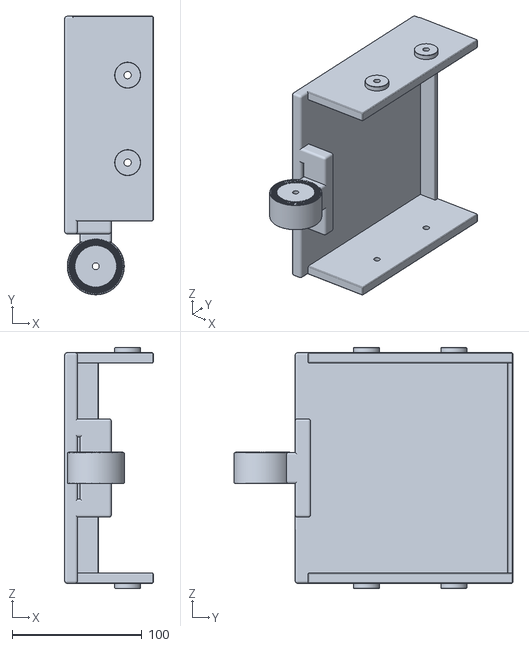
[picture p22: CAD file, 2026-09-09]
print/Part_3_Cradle.stl
68.4 x 215.0 x 186.0

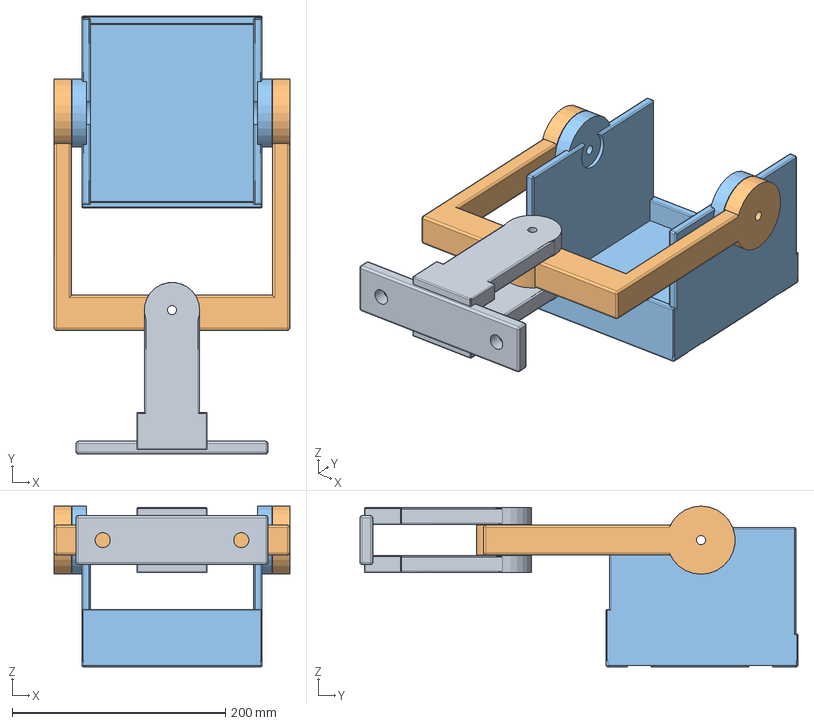
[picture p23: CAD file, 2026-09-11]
rail-mount/cad/eris_rail_mount.step
221.0 x 411.0 x 151.0 mm

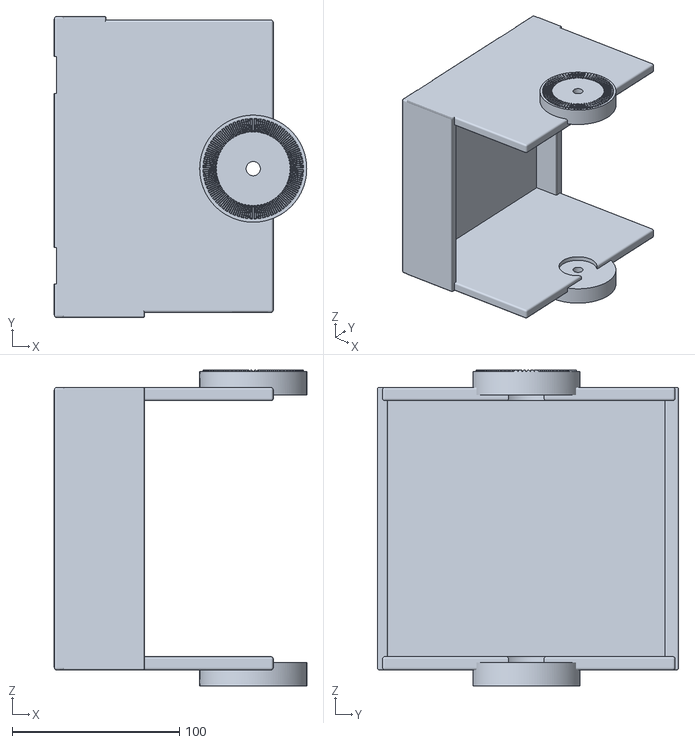
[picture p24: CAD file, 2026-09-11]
rail-mount/print/Eris_Cradle.stl
151.0 x 180.0 x 188.8

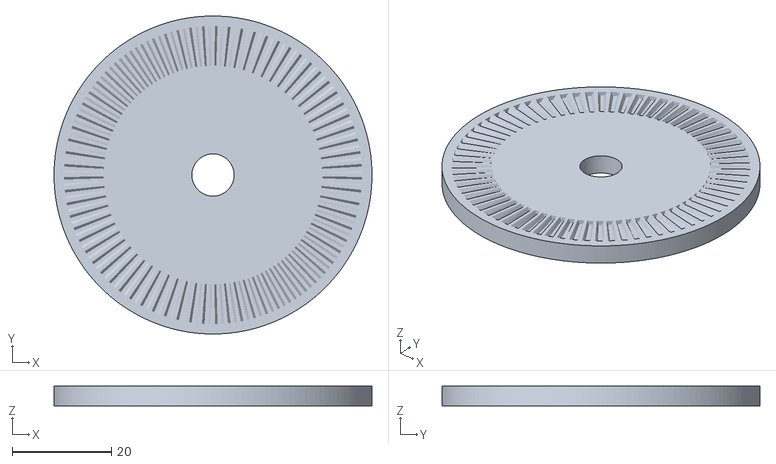
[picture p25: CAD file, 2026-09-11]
rail-mount/print/fit-coupons/Female_5deg.stl
64.0 x 64.0 x 4.00

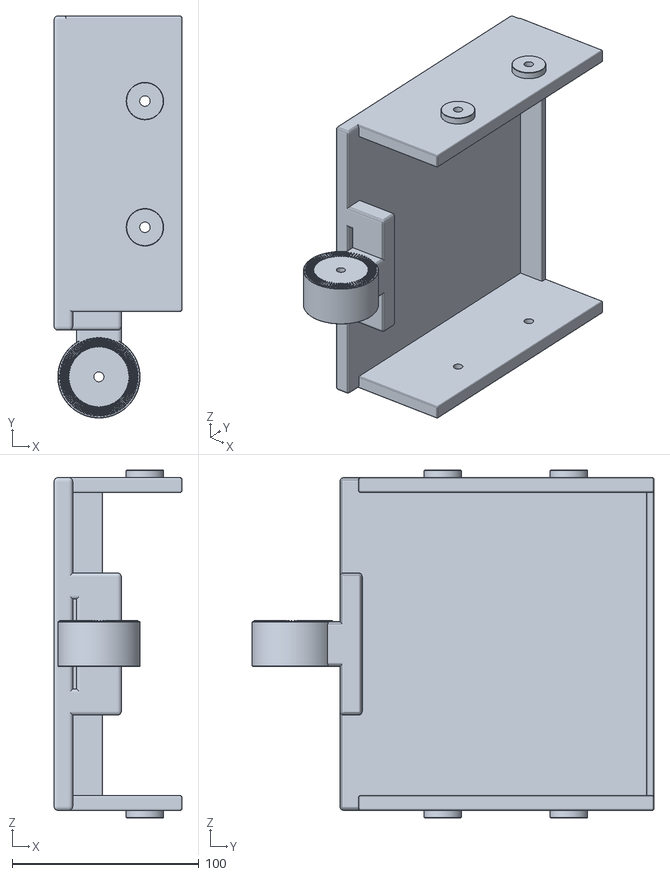
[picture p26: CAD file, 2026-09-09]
output_blender/Part_3_Cradle.stl
68.4 x 215.0 x 186.0

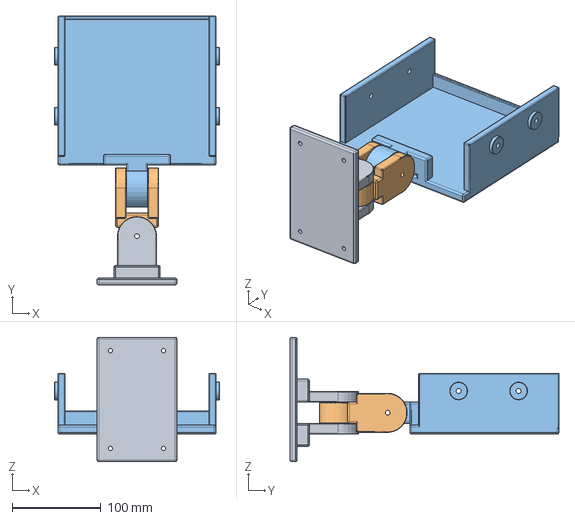
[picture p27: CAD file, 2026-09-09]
output_freecad/surround_mount.step
186.0 x 303.0 x 140.0 mm

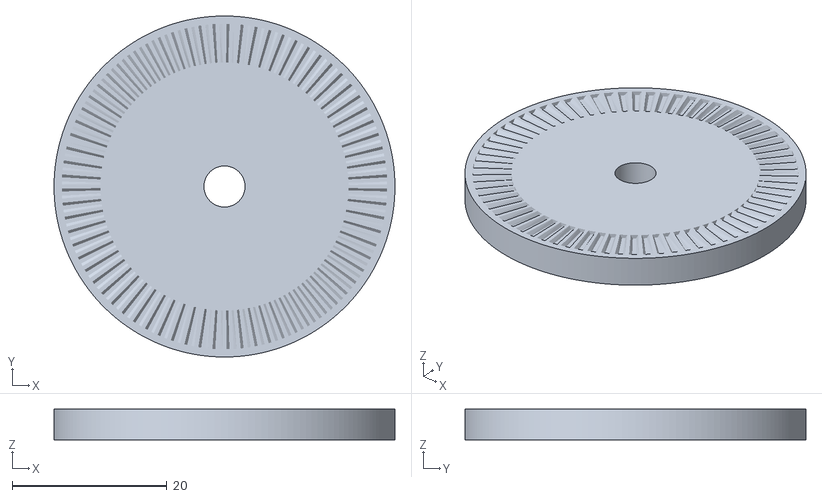
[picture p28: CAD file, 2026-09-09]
print/fit-coupons/Tilt_Female_Coupon.stl
44.0 x 44.0 x 4.00

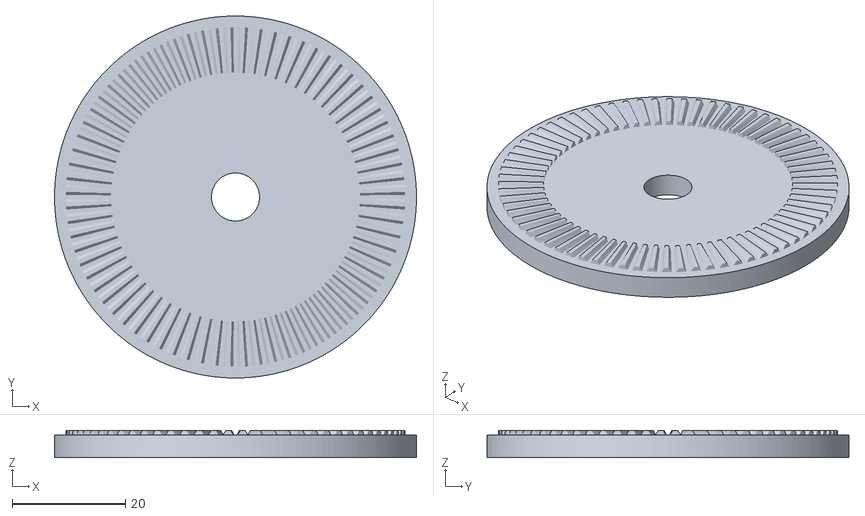
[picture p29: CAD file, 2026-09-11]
rail-mount/print/fit-coupons/Male_5deg.stl
64.0 x 64.0 x 4.80

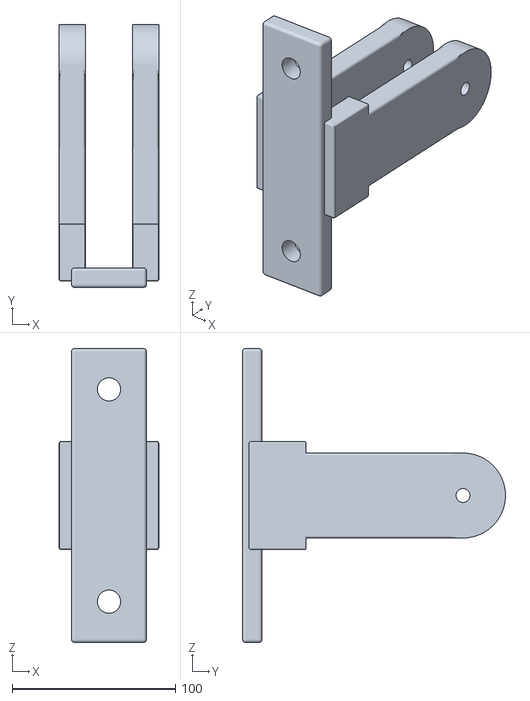
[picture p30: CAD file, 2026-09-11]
rail-mount/print/Rail_Shoe.stl
61.0 x 161.0 x 180.0

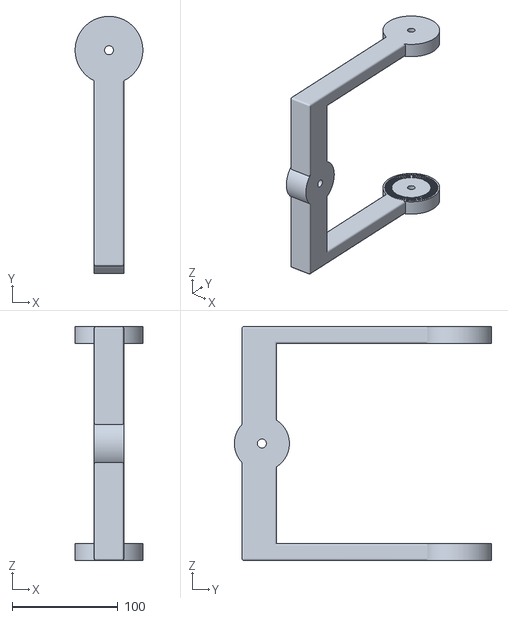
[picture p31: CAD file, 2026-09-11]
rail-mount/print/Pan_Yoke.stl
64.0 x 243.0 x 221.0

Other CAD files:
output_freecad/interactive_assembly_visible.FCStd
print/Part_2_SwivelArm.stl
output_blender/Part_1_WallPlate.stl
output_blender/interactive_assembly.blend
output_blender/surround_mount.blend
output_freecad/Part_2_SwivelArm.stl
output_freecad/surround_mount.FCStd
rail-mount/cad/eris_rail_mount.FCStd
rail-mount/print/fit-coupons/Tilt_Bolt_Tool_Access.stl
rail-mount/render/mount_inspection.blend
showcase/living_room.blend
showcase/mount_animation.blend
showcase/tilt_detail.blend

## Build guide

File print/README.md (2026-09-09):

# Compact speaker mount — print files

Print 2 × each STL for a pair of speakers (six printed parts total).
These are the compact revision 3 FreeCAD exports, already oriented on their X sides.
Import in millimetres and do not auto-scale.

| File | Quantity for pair | Bounding box X × Y × Z |
|---|---:|---|
| Part_1_WallPlate.stl | 2 | 140 × 77 × 90 mm |
| Part_2_SwivelArm.stl | 2 | 44 × 99 × 48.6 mm |
| Part_3_Cradle.stl | 2 | 68.4 × 215 × 186 mm |

PETG or ASA; 0.4 mm nozzle; 0.20 mm layers; 6 walls; 6–8 top/bottom layers;
45–50% gyroid. Use local solid infill around joints and insert bosses.
Supports are required beneath ears, raised rails and horizontal bores; inspect the
slicer preview and enable internal supports where needed. Use a brim. A 250 mm
bed is recommended; a 220 mm bed has only 5 mm spare along the cradle length.
Check your slicer's estimated print duration before planning an overnight batch.

Read the root README for the M5 joint hardware, M4 inserts, pressure feet, foam,
wall fixings and assembly. The insert bore is 5.6 mm: confirm it matches your inserts.
The terminal panel is assumed 40 mm wide, 60 mm tall, starting 40 mm above the
cabinet bottom, with 30 mm rear plug projection; panel height/projection are unconfirmed.
This is a prototype without a load rating; inspect and load-test before wall use.

## Indexed tilt interface

The up/down pivot now seats in **5° steps** using a 72-tooth mating ring. Pan stays
smooth and continuously adjustable. Reprint both arm and cradle; the wall plate
is unchanged. Do not mix smooth revision 2 and toothed revision 3 mating parts.

Print `fit-coupons/Tilt_Female_Coupon.stl` and `fit-coupons/Tilt_Male_Coupon.stl`
first, with toothed faces up. Inspect the slicer for preserved teeth. Use
0.10–0.12 mm layers through the teeth and check fit without forcing. The minimum
nominal crest width is about 0.42 mm, so a 0.4 mm nozzle is at the fine-feature
limit. Adjust the process or use a smaller nozzle if details are lost.

The arm print orientation is flipped from revision 2 to point its toothed face
up. Keep support contact off the teeth and route supports for the opposing ear
from smooth areas or the bed. The cradle also has its toothed face pointing up.

Support the speaker, loosen the tilt bolt, slide the cradle toward the smooth
cheek to clear the teeth, choose a 5° position, seat and retighten. Do not ratchet
the teeth under load. Nominal release travel from seated is 0.6 mm. Printed fit,
tooth strength and holding performance remain unverified.

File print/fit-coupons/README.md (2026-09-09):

# Tilt-interface fit coupons

Two 44 mm discs with the same revision 3, 72-tooth profiles and 5.3 mm bores.
Import in millimetres. Both files are already oriented with teeth facing up.
The female disc is 4 mm thick; the male is 4.45 mm including its tooth relief.

Use the intended filament and 0.10–0.12 mm layers through the teeth. Verify the
slicer preserves each ridge. Bring the faces together by hand: they should seat
at 5° increments and disengage when separated axially. Check for rocking,
incomplete seating and damaged crests. Do not force or sand away the tooth form.

Passing this fit check does not establish the complete mount's load capacity.

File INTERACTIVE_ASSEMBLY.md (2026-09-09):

# Move the mount interactively

## Blender

Open `output_blender/interactive_assembly.blend`.

1. `AIM_CONTROLS` is preselected. Select it in the Outliner if needed.
2. In the **Object Properties** tab (orange square icon), expand **Custom Properties**.
3. Drag or type **Pan_degrees** (−60…60) and **Tilt_degrees** (−30…0, snapped to 5° steps).
4. Set both to zero to return to level and straight.

The wall stays fixed; the arm swivels around the vertical pin; the cradle, cabinet, terminal panel and clamp hardware tilt around the horizontal pin and follow pan. The controls use native Blender drivers and rotation constraints. No add-on or Python auto-run permission is required. Demonstration animation was removed so moving the timeline cannot reset your pose. Mesh transforms are locked against accidental movement; adjust the two controls instead.

## FreeCAD

Open `output_freecad/interactive_assembly_visible.FCStd` (the standard `interactive_assembly.FCStd` has also been corrected). Close the earlier copy first, then open this file and press **V, F** to fit the whole assembly.

1. Select **AIM CONTROLS — edit Pan / Tilt below** in the model tree.
2. In the **Data** property tab, expand **Aiming**.
3. Change **Pan** (−60…60) and **Tilt** (−30…0, snapped to 5° steps); press Enter to apply.
4. Set both to zero to reset. If automatic recompute is disabled, press F5.

For live mouse dragging, sliders and part colors, open `Open_Interactive_Assembly.FCMacro` through **Macro → Macros → select the file → Execute**. The macro opens the assembly and adds a **Speaker — Pan & Tilt** dock with a drag pad, sliders and a reset button. Hold the left mouse button in the pad: drag left/right for pan and up/down for tilt. The pan updates continuously; tilt snaps to 5° steps. Keep the macro beside the output folders. The native property controls work without running it. Entered tilt values are rounded to the nearest 5° by the placement expression.

The FreeCAD assembly uses nested `App::Part` groups and native placement expressions, not Assembly-workbench solver joints. No additional workbench or custom Python proxy is needed. It includes the cabinet and provisional terminal panel. Its printed-part shapes are snapshots of the compact design, so posing is quick and does not rebuild the geometry. To update geometry, regenerate the parametric source and rerun `make_interactive_freecad.py`.

Both files open at zero pan/tilt and can save your chosen pose. These are kinematic previews, not simulations of flex, friction or load capacity. Tilt controls jump between engaged positions; loosen and axially disengage the real tooth interface before adjustment. The original manufacturing models and STL print orientations remain in their existing files.

Validation: native FreeCAD placements and evaluated Blender driver transforms were compared against independent rotation matrices at (pan, requested tilt) = (0,0), (60,−30), (−60,−30), and (25,−12); the last request now produces −10° tilt. The FreeCAD file was also reopened and checked at (45,−20). The original revision 2 FreeCAD drag pad was exercised in a live GUI session: simulated press/move/release events updated pan and tilt, then restored the starting pose. That historical check is saved in `live_drag_validation.json`; revision 3 controls additionally snap tilt to 5°.

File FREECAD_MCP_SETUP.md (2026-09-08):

# FreeCAD MCP connection

Detection on 2026-09-08: **no FreeCAD MCP tools are exposed to this agent**, and no FreeCAD server entry appears in this machine's Codex configuration. FreeCAD 1.1.3, Blender 5.2.0 and `/usr/bin/uvx` are installed. Blender MCP tools are exposed. The deliverables were generated using local CAD runtimes; no FreeCAD MCP connection was needed or installed.

Use the [neka-nat FreeCAD MCP bridge](https://github.com/neka-nat/freecad-mcp). It comprises a FreeCAD GUI addon (RPC endpoint) and a separate Python MCP process. `/usr/bin/FreeCAD` itself does **not** speak MCP over stdio.

1. Install its addon for this Arch Linux / FreeCAD 1.1 environment:

```bash
git clone https://github.com/neka-nat/freecad-mcp.git ~/Projects/freecad-mcp
mkdir -p ~/.local/share/FreeCAD/v1-1/Mod
cp -r ~/Projects/freecad-mcp/addon/FreeCADMCP ~/.local/share/FreeCAD/v1-1/Mod/
```

2. Launch `/usr/bin/FreeCAD`, choose the **MCP Addon** workbench, then **Start RPC Server** in its toolbar. Leave FreeCAD running. Keep the bridge local; remote access is unnecessary.

3. Add this to an MCP client supporting `mcpServers` JSON, merging with existing entries:

```json
{
  "mcpServers": {
    "freecad": {
      "command": "/usr/bin/uvx",
      "args": ["freecad-mcp", "--only-text-feedback"]
    }
  }
}
```

For this Codex installation, the equivalent entry in `~/.codex/config.toml` is:

```toml
[mcp_servers.freecad]
command = "/usr/bin/uvx"
args = ["freecad-mcp", "--only-text-feedback"]
```

4. Restart the agent/client. Confirm FreeCAD tools appear, then ask it to create a temporary document and execute:

```python
import FreeCAD as App
import Part
doc = App.newDocument('MCP_Connection_Test')
obj = doc.addObject('PartDesign::Body', 'TestBody')
feature = obj.newObject('PartDesign::Feature', 'TestCube')
feature.Shape = Part.makeBox(10, 10, 10)
doc.recompute()
print(feature.Shape.Volume)  # Expected 1000 mm^3
```

Confirm the returned value and visible cube. If tools appear but RPC calls fail, check the addon and running GUI; if tools are absent, check client config and restart. Close the temporary document afterward. This setup guide was verified against upstream instructions; installation and connection testing were not performed here.

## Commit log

2026-09-08 Add compact speaker mount CAD, printable STLs, and live assemblies
    [Part_1_WallPlate.stl, Part_2_SwivelArm.stl, Part_3_Cradle.stl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]
2026-09-09 Create Blender living-room surround mount showcase
    [living_room.blend]
2026-09-09 Index the tilt pivot in 5-degree steps and add motion showcase
    [Part_1_WallPlate.stl, Part_2_SwivelArm.stl, Part_3_Cradle.stl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]
2026-09-11 Add the Eris E3.5 rail mount, revision 1.1
    An adaptation of the mount for the dorm-room wooden rail: the fixings pass
    through the wood into concrete and every fixing axis stays inside the rail's
    50 mm outline. Sized for the 141 x 162 x 210 mm Eris E3.5 cabinet, with
    continuous pan and indexed downward tilt in 5-degree steps.
    Revision 1.1 opens the two inner tilt-bolt recesses to 32 mm so a spanner can
    counterhold the heads, and adds a 36 mm tool window in the side foam. Pivot
    bores, teeth, cabinet fit and movement envelope are unchanged, so only the
    cradle needs reprinting if 1.0 is already on the wall.
    Includes the FreeCAD assembly, STEP, three print files per speaker, fit
    coupons, dimens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
    [Eris_Cradle.stl, Female_5deg.stl, Male_5deg.stl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]
